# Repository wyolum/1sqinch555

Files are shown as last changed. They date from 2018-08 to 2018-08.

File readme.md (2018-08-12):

# 1sqinch555
3x3x3 LED cube without using microcontroller.
Uses the awesome 555 timer and a 14 bit ripple counter (4020).
9 outputs from the counter drive sets of 3 LEDs in series.
Works off 9V battery.
Possible submission for 1 square inch competition at HAD.

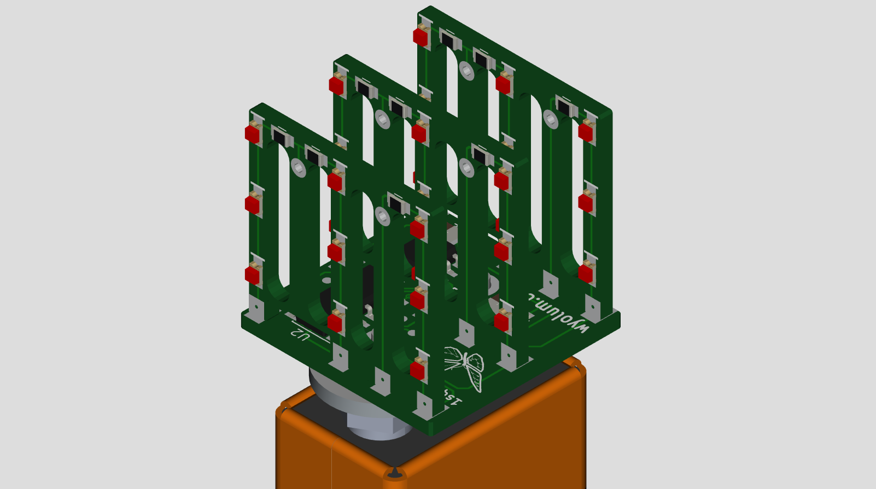
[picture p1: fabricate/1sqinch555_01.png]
1sqinch555


License
-------
[CERN Open Hardware Licence v1.2 ]

[CERN Open Hardware Licence v1.2 ]:http://www.ohwr.org/attachments/2388/cern_ohl_v_1_2.txt

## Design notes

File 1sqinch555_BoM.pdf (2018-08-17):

1sqinch555_pcb_BoM

Page 1

No | Quantity Reference | Value | Footprint
1 | 1 | BT1 | 9V | 9V_clip_968
2 | 1 | C1 | 10uF | C_0805
3 | 1 | C2 | 10nF | C_0805
4 | 27 | D1,D2,D3,D4,D5,D6,D7,D8,D 9,D10,D11,D12,D13,D14,D15 ,D16,D17,D18,D19,D20,D21, D22,D23,D24,D25,D26,D27 | LED | D_0805
5 | 1 | R1 | 33k | R_0805
6 | 9 | R2,R3,R4,R5,R6,R7,R8,R9,R 10 | 300 | R_0805
7 | 1 | U1 | LM555 | SOIC-8_3.9x4.9mm_Pitch1.27mm
8 | 1 | U2 | 4020 | SOIC-16_3.9x9.9mm_Pitch1.27mm

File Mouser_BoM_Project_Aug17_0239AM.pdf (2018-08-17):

1SQINCH555
Mouser No | Mfr. No | Manufacturer
534-967 | 967 | Keystone Electronics
595-SA555DR | SA555DR | Texas Instruments
771-HEC4020BT118 | HEC4020BT,118 | Nexperia
667-ERJ-6ENF3302V | ERJ-6ENF3302V | Panasonic
71-CRCW0805300RJNEA | CRCW0805300RJNEA | Vishay
77-VJ0805Y103MXXCBC | VJ0805Y103MXXCW1BC Vishay
710-150080RS75000 | 150080RS75000 | Wurth Electronics
963-TMK212BBJ106MG-T | TMK212BBJ106MG-T | Taiyo Yuden

Customer No

Description
9V Battery Snaps & Contacts 968 w/ .120 legs
Timers & Support Products Precision
Counter ICs 14-ST BINARY COUNTER
Thick Film Resistors - SMD 0805 33Kohms 1% AEC-Q200
Thick Film Resistors - SMD 1/8watt 300ohms 5%
Multilayer Ceramic Capacitors MLCC - SMD/SMT 0805 0.01uF 25volts X7R 20% Standard LEDs - SMD WL-SMCW SMDMono TpVw Waterclr 0805 Red Multilayer Ceramic Capacitors MLCC - SMD/SMT 10uF 25V X5R 20% 0805

RoHS | Lifecycle | Order Qty. Price (USD)Ext.: (USD)
RoHS Compliant | | 5 $1.11 | $5.55
RoHS Compliant | | 1 $0.39 | $0.39
RoHS Compliant | | 1 $0.67 | $0.67
RoHS Compliant By Exemption | | 10 $0.046 | $0.46
RoHS Compliant By Exemption | | 10 $0.042 | $0.42
RoHS Compliant | | 10 $0.10 | $1.00
RoHS Compliant | | 30 $0.171 | $5.13
RoHS Compliant | New Product | 10 $0.077 | $0.77

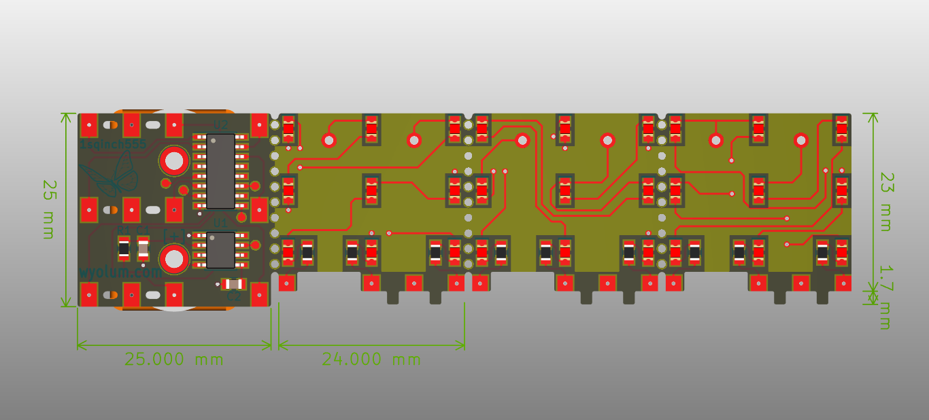
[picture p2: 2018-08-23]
render/1sqinch555_03.png

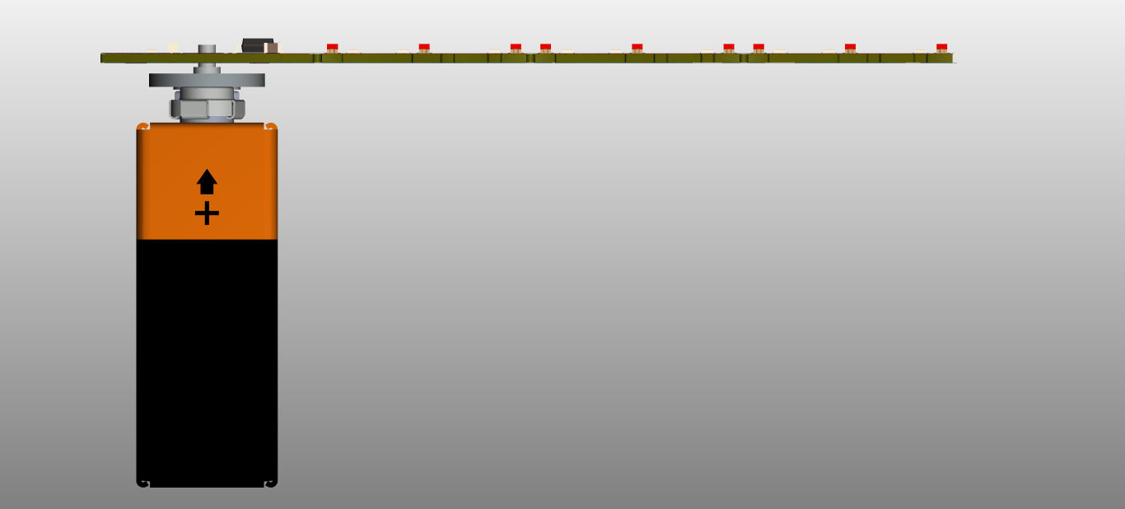
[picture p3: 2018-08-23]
render/1sqinch555_04.png

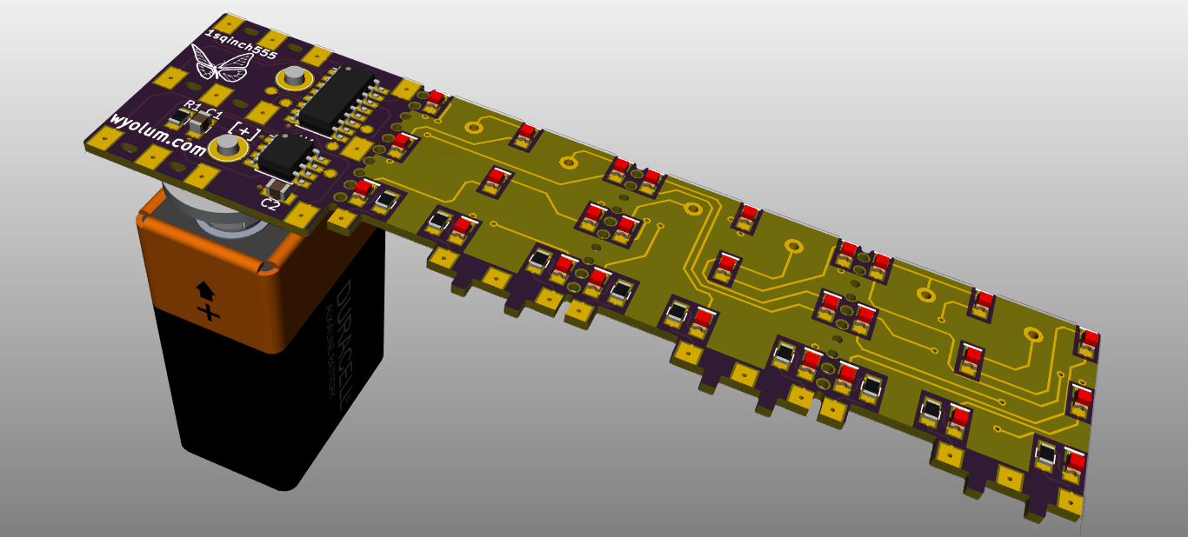
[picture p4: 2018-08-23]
render/1sqinch555_02.png

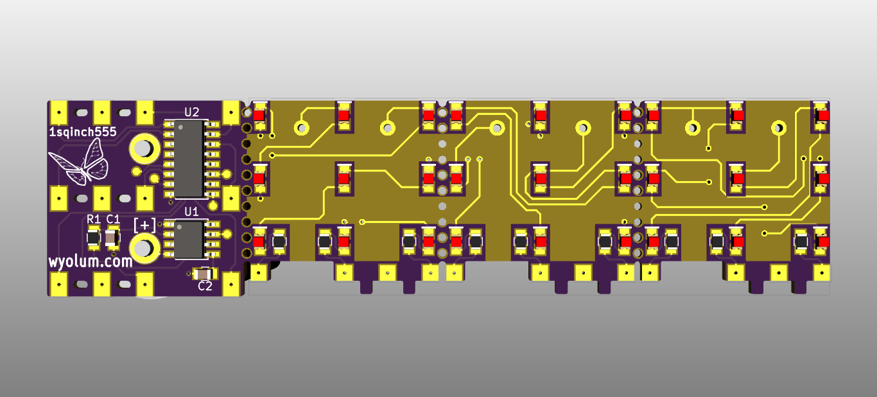
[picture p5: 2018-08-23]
render/1sqinch555_01.png

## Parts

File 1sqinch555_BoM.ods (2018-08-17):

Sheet: 1sqinch555_pcb_BoM
No | Quantity | Reference | Value | Footprint
1 | 1 | BT1 | 9V | 9V_clip_968
2 | 1 | C1 | 10uF | C_0805
3 | 1 | C2 | 10nF | C_0805
4 | 27 | D1,D2,D3,D4,D5,D6,D7,D8,D9,D10,D11,D12,D13,D14,D15,D16,D17,D18,D19,D20,D21,D22,D23,D24,D25,D26,D27 | LED | D_0805
5 | 1 | R1 | 33k | R_0805
6 | 9 | R2,R3,R4,R5,R6,R7,R8,R9,R10 | 300 | R_0805
7 | 1 | U1 | LM555 | SOIC-8_3.9x4.9mm_Pitch1.27mm
8 | 1 | U2 | 4020 | SOIC-16_3.9x9.9mm_Pitch1.27mm

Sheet: 1sqinch555_sch_BoM
No | Quantity | Reference | Value | Footprint
1 | 1 | BT1 | 9V | 1sqinch555_fp:9V_clip_968
2 | 1 | C1 | 10uF | 1sqinch555_fp:C_0805
3 | 1 | C2 | 10nF | 1sqinch555_fp:C_0805
4 | 27 | D1,D2,D3,D4,D5,D6,D7,D8,D9,D10,D11,D12,D13,D14,D15,D16,D17,D18,D19,D20,D21,D22,D23,D24,D25,D26,D27 | LED | 1sqinch555_fp:D_0805
5 | 1 | R1 | 33k | 1sqinch555_fp:R_0805
6 | 9 | R2,R3,R4,R5,R6,R7,R8,R9,R10 | 300 | 1sqinch555_fp:R_0805
7 | 1 | U1 | LM555 | 1sqinch555_fp:SOIC-8_3.9x4.9mm_Pitch1.27mm
8 | 1 | U2 | 4020 | 1sqinch555_fp:SOIC-16_3.9x9.9mm_Pitch1.27mm

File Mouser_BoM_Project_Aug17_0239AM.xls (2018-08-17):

1SQINCH555
Mouser No | Mfr. No | Manufacturer | Customer No | Description | RoHS | Lifecycle | Order Qty. | Price (USD) | Ext.: (USD)
534-967 | 967 | Keystone Electronics |  | 9V Battery Snaps & Contacts 968 w/ .120 legs | RoHS Compliant |  | 5 | $1.11 | $5.55
595-SA555DR | SA555DR | Texas Instruments |  | Timers & Support Products Precision | RoHS Compliant |  | 1 | $0.39 | $0.39
771-HEC4020BT118 | HEC4020BT,118 | Nexperia |  | Counter ICs 14-ST BINARY COUNTER | RoHS Compliant |  | 1 | $0.67 | $0.67
667-ERJ-6ENF3302V | ERJ-6ENF3302V | Panasonic |  | Thick Film Resistors - SMD 0805 33Kohms 1% AEC-Q200 | RoHS Compliant By Exemption |  | 10 | $0.046 | $0.46
71-CRCW0805300RJNEA | CRCW0805300RJNEA | Vishay |  | Thick Film Resistors - SMD 1/8watt 300ohms 5% | RoHS Compliant By Exemption |  | 10 | $0.042 | $0.42
77-VJ0805Y103MXXCBC | VJ0805Y103MXXCW1BC | Vishay |  | Multilayer Ceramic Capacitors MLCC - SMD/SMT 0805 0.01uF 25volts X7R 20% | RoHS Compliant |  | 10 | $0.10 | $1.00
710-150080RS75000 | 150080RS75000 | Wurth Electronics |  | Standard LEDs - SMD WL-SMCW SMDMono TpVw Waterclr 0805 Red | RoHS Compliant |  | 30 | $0.171 | $5.13
963-TMK212BBJ106MG-T | TMK212BBJ106MG-T | Taiyo Yuden |  | Multilayer Ceramic Capacitors MLCC - SMD/SMT 10uF 25V X5R 20% 0805 | RoHS Compliant | New Product | 10 | $0.077 | $0.77

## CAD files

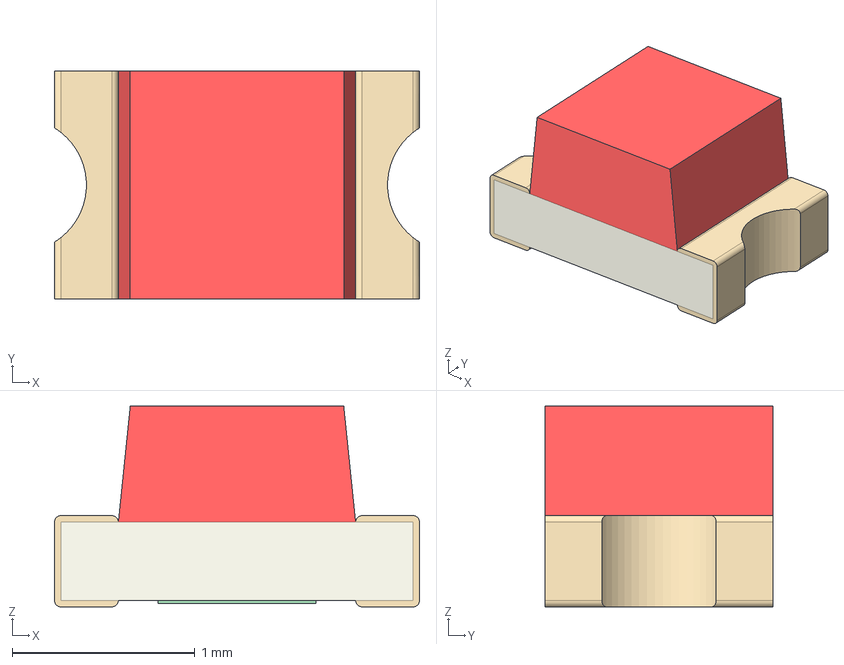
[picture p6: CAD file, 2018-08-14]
3d_modules/LED_0805_2012Metric_Castellated.step
2.00 x 1.25 x 1.10 mm

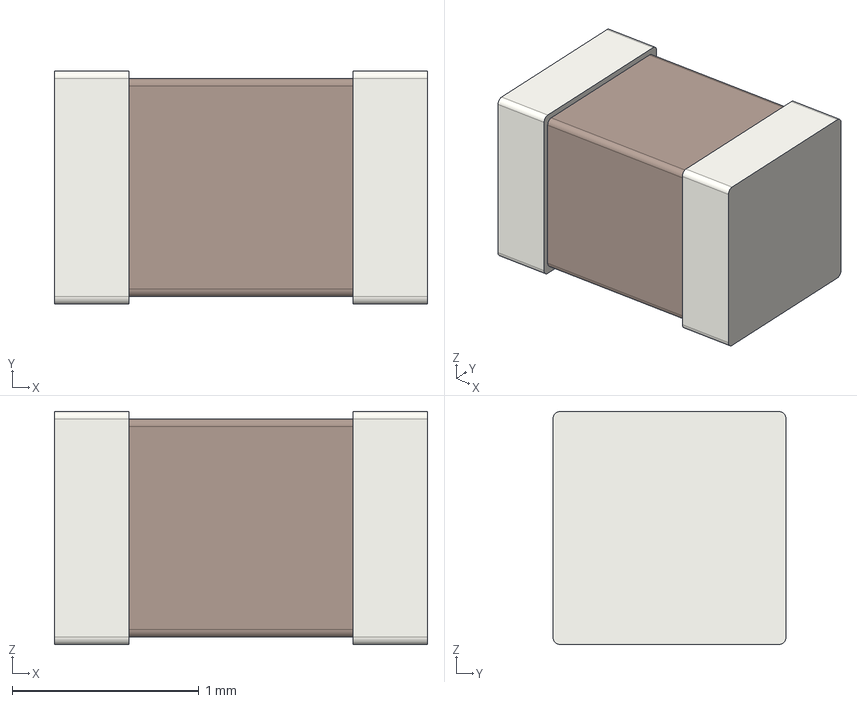
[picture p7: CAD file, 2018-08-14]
3d_modules/C_0805_2012Metric.step
2.00 x 1.25 x 1.25 mm

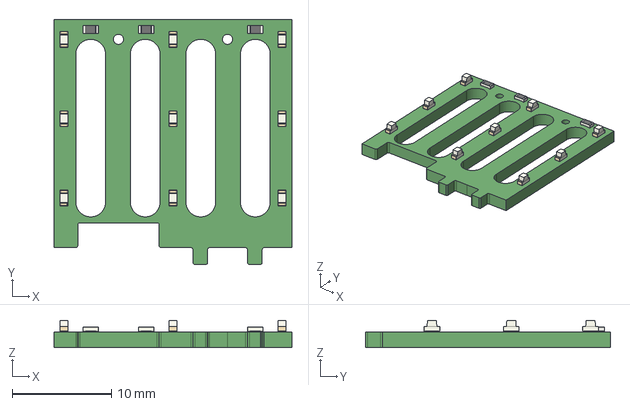
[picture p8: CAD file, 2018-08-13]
fabricate/1sqinch555_LED.step
24.0 x 24.7 x 2.75 mm

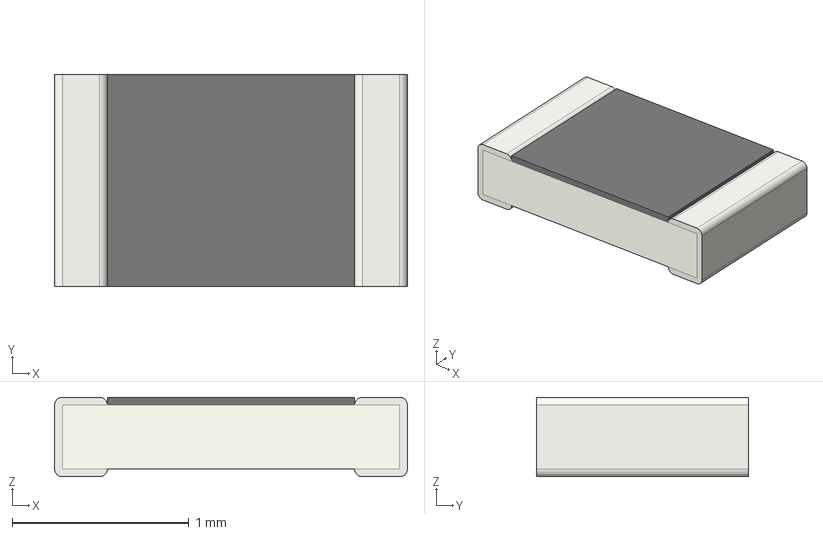
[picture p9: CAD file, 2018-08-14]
3d_modules/R_0805_2012Metric.step
2.00 x 1.20 x 0.45 mm

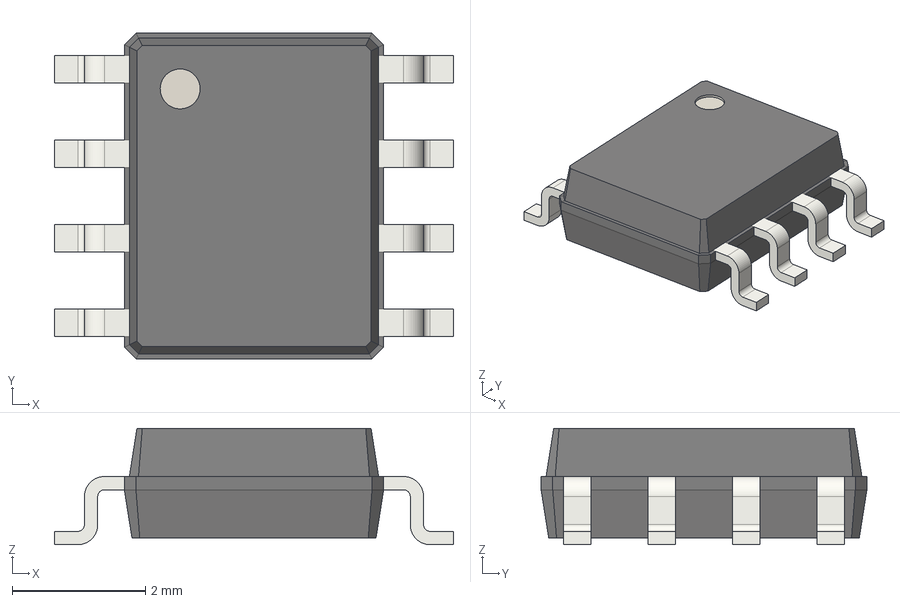
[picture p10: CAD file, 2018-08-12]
3d_modules/SOIC-8_3.9x4.9mm_P1.27mm.step
6.00 x 4.90 x 1.75 mm

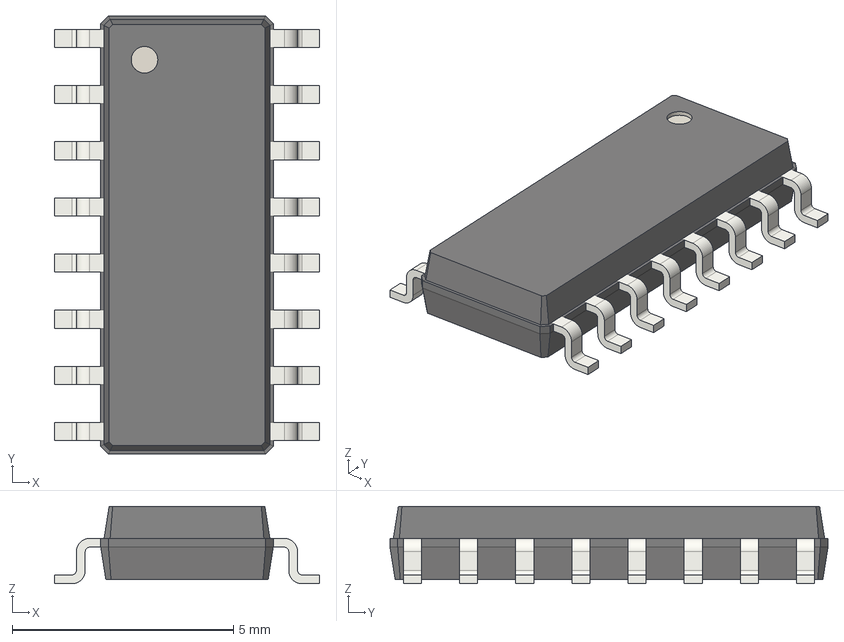
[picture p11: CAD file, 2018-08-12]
3d_modules/SOIC-16_3.9x9.9mm_P1.27mm.step
6.00 x 9.90 x 1.75 mm

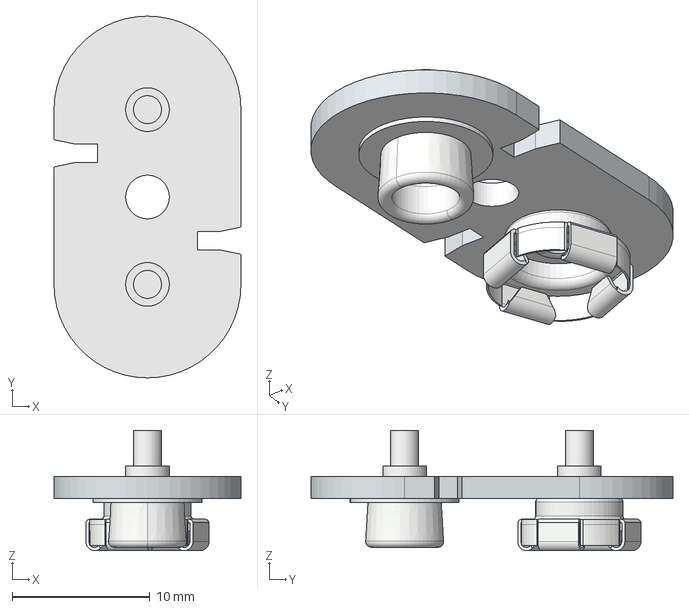
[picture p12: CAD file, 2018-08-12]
3d_modules/batt_9V.step
13.6 x 26.3 x 8.75 mm

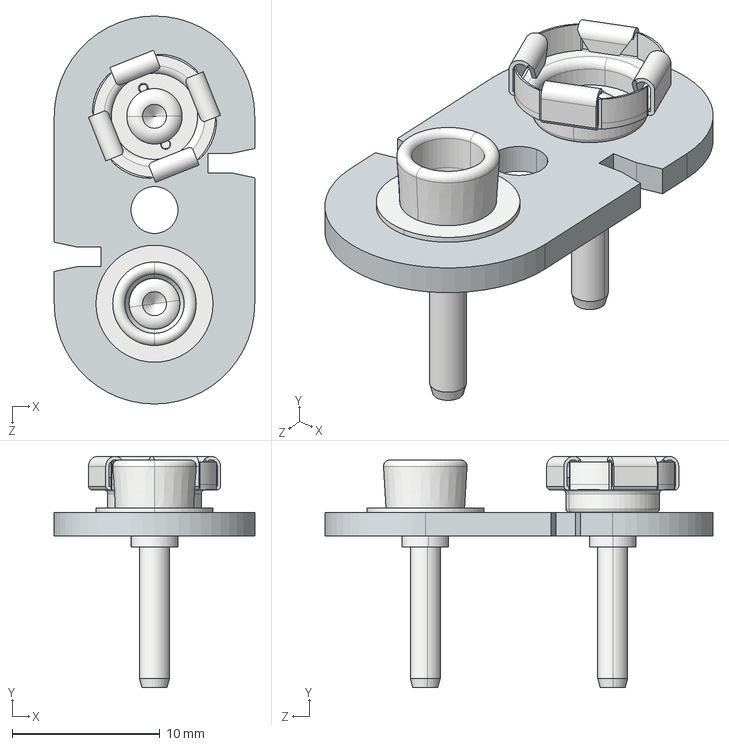
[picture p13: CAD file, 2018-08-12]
3d_modules/keystone-PN968.stp
13.6 x 15.7 x 26.3 mm

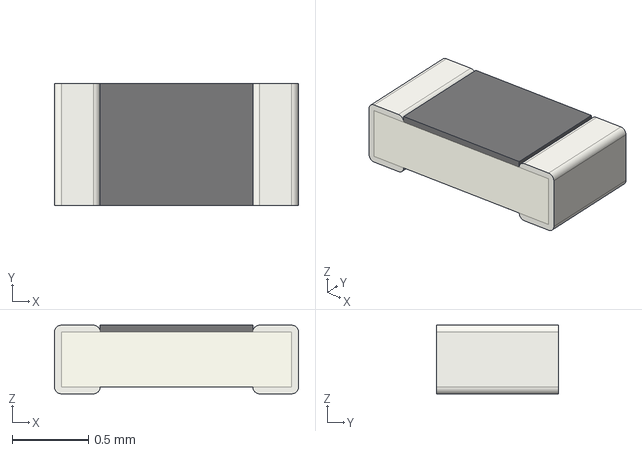
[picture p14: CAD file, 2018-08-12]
3d_modules/R_0603_1608Metric.step
1.60 x 0.8 x 0.45 mm

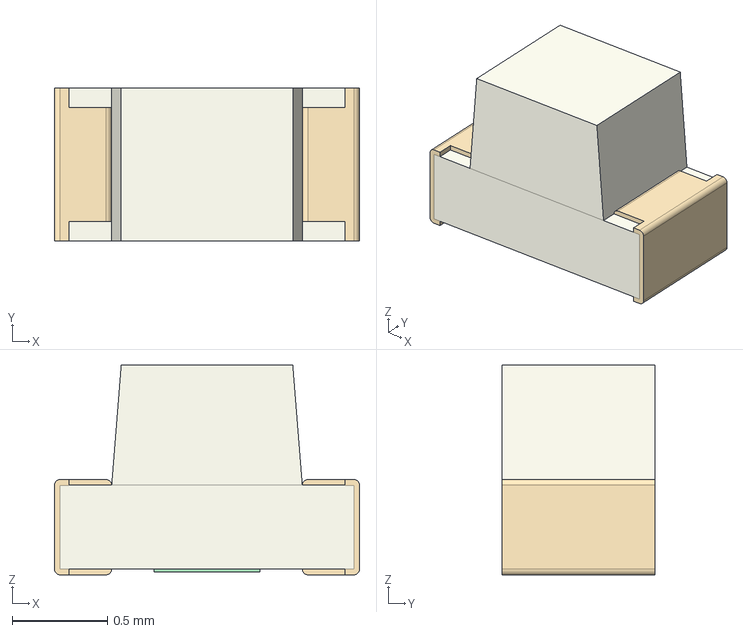
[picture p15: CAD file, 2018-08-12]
3d_modules/LED_0603_1608Metric.step
1.60 x 0.8 x 1.10 mm

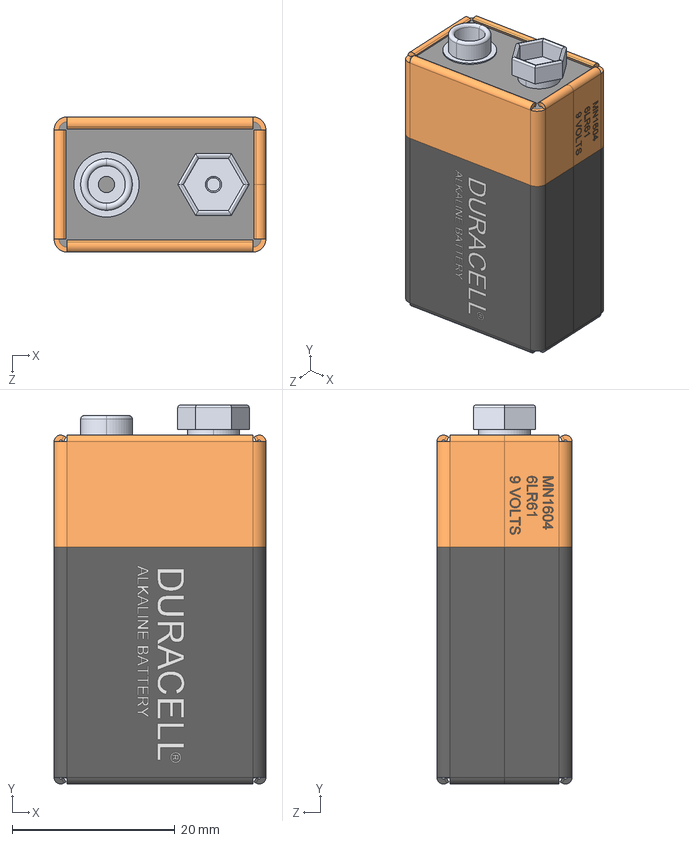
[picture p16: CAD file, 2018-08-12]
3d_modules/9V Duracell Battery.step
26.0 x 46.5 x 16.6 mm

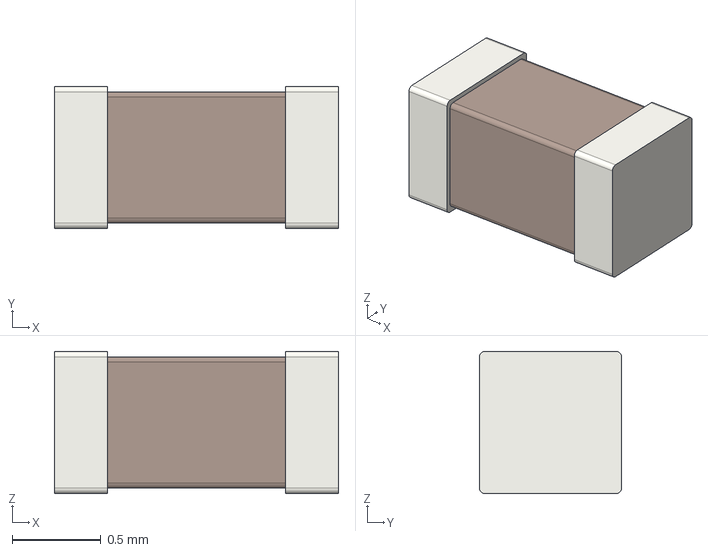
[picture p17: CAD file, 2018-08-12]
3d_modules/C_0603_1608Metric.step
1.60 x 0.8 x 0.8 mm

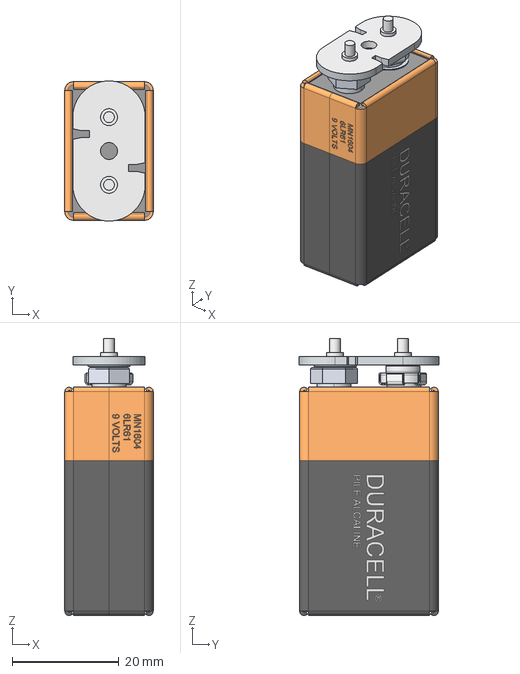
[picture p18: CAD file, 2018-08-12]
3d_modules/batt_9V_cp.step
16.6 x 26.3 x 52.0 mm

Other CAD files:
fabricate/1sqinch555.fcstd

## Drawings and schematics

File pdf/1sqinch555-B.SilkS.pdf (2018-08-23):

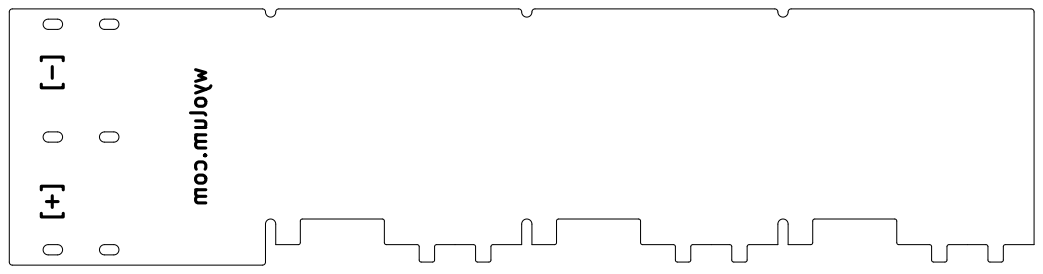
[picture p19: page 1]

File: 1sqinch555.kicad_pcb Sheet: wyolum.com [+] [-]

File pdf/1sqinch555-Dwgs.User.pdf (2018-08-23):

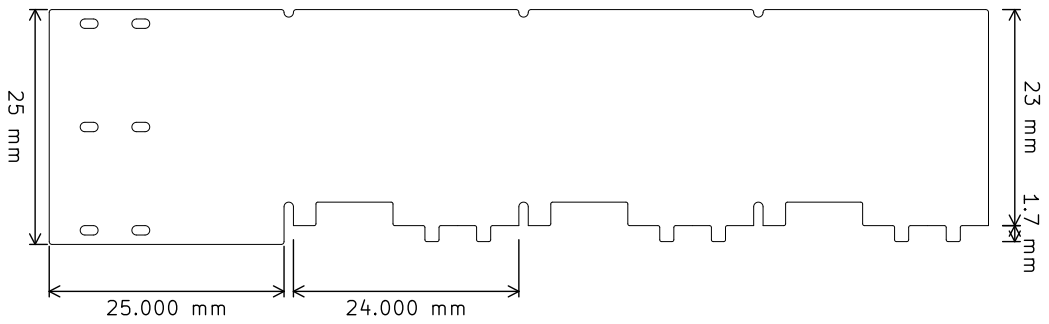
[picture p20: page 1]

File: 1sqinch555.kicad_pcb Sheet: 1.7 mm 23 mm

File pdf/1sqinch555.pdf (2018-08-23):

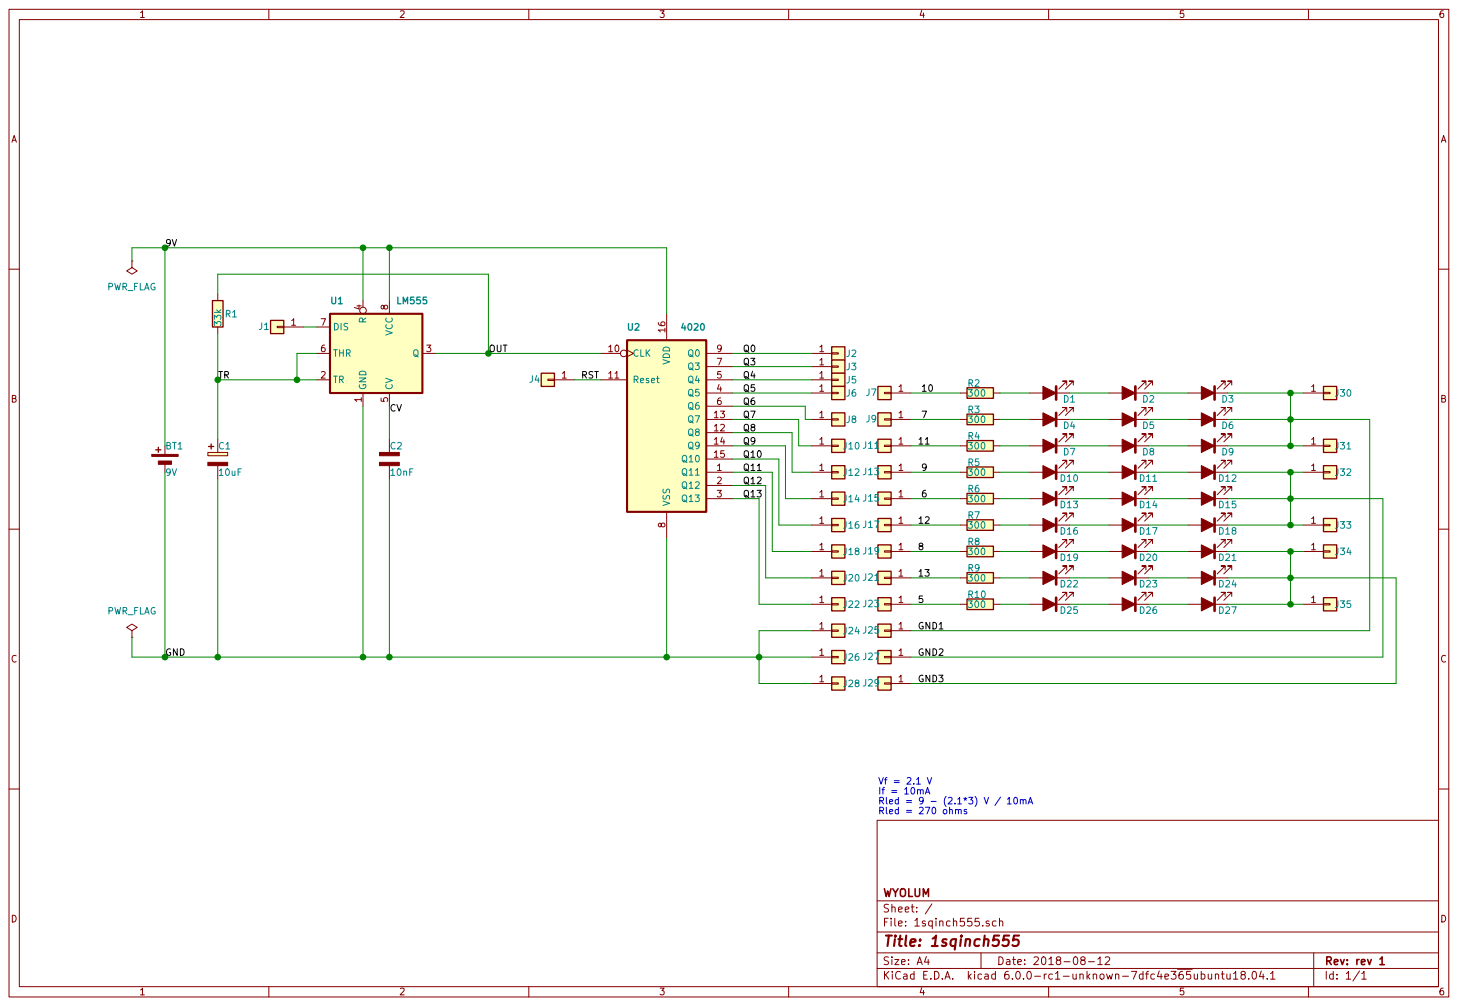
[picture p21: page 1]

If = 10mA Rled = 9 - (2.1*3) V / 10mA Rled = 270 ohms

File: 1sqinch555.sch Sheet: / WYOLUM

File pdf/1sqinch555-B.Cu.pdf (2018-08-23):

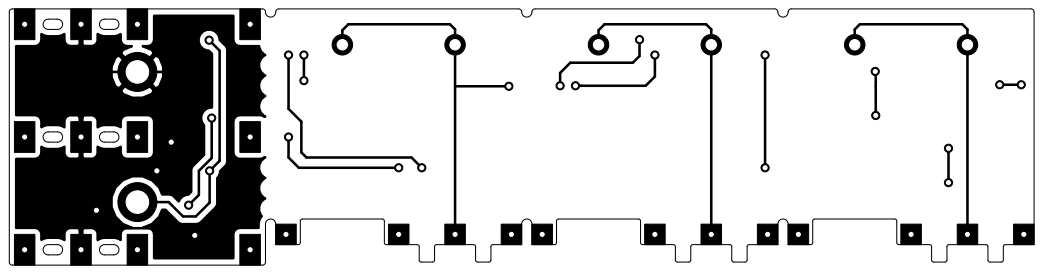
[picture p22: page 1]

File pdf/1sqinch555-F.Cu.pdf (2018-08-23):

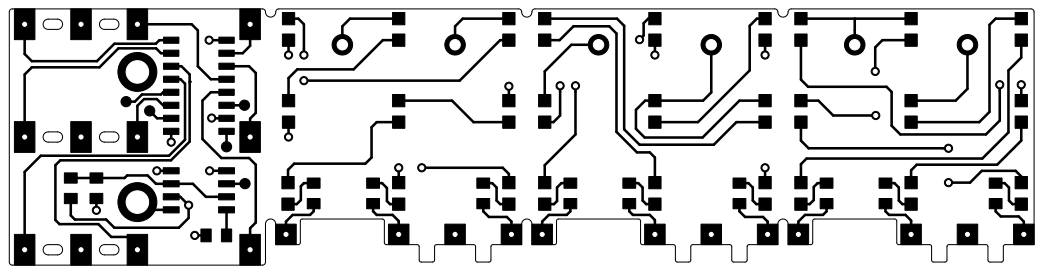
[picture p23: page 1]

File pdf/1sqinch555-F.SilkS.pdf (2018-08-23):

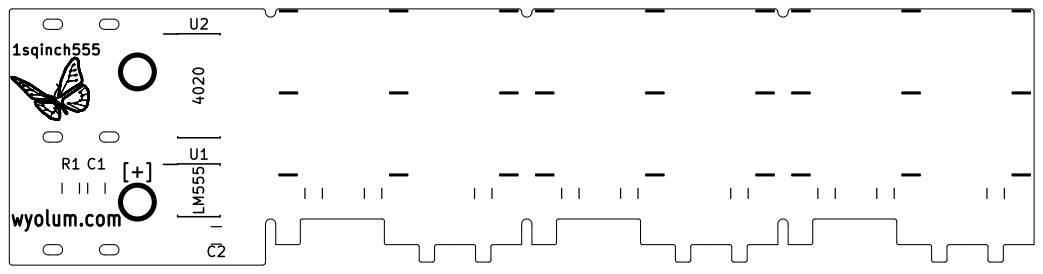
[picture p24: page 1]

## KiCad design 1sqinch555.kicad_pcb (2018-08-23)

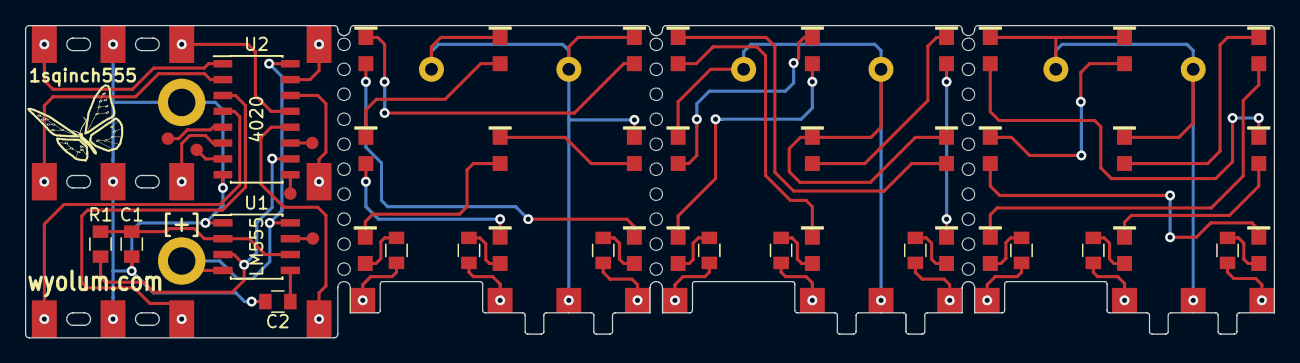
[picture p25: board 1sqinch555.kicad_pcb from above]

Board: 2 copper layers, 100.0 x 25.0 mm, 78 parts (0 on the bottom side), 58 nets.

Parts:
BT1: 9V; 9V_clip_968
C1: 10uF; C_0805
C2: 10nF; C_0805
D1, D2, D3, D4, D5, D6, D7, D8, D9, D10, D11, D12, D13, D14, D15, D16, D17, D18, D19, D20, D21, D22, D23, D24, D25, D26, D27: LED; LED-0805
G1: Logo-WL3
J1, J2, J3, J4, J5: Conn_01x01; pad_smd_1mm
J6, J8, J10, J12, J14, J16, J18, J20, J22, J24, J26, J28: Conn_01x01; pad_3x2mm_smd
J7, J9, J11, J13, J15, J17, J19, J21, J23, J25, J27, J29: Conn_01x01; pad_2x2mm
J30, J31, J32, J33, J34, J35: Conn_01x01; Plated_Hole_d1.0mm
R1: 33k; R_0805
R2, R3, R4, R5, R6, R7, R8, R9, R10: 300; R_0805
U1: LM555; SOIC-8_3.9x4.9mm_Pitch1.27mm
U2: 4020; SOIC-16_3.9x9.9mm_Pitch1.27mm

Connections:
/5: J23.1, R10.2
/6: J15.1, R6.2
/7: J9.1, R3.2
/8: J19.1, R8.2
/9: J13.1, R5.2
/9V: BT1.1, U1.4, U1.8, U2.16
/10: J7.1, R2.2
/11: J11.1, R4.2
/12: J17.1, R7.2
/13: J21.1, R9.2
/CV: C2.1, U1.5
/GND: BT1.2, C1.2, C2.2, J24.1, J26.1, J28.1, U1.1, U2.8
/GND1: D3.1, D6.1, D9.1, J25.1, J30.1, J31.1
/GND2: D12.1, D15.1, D18.1, J27.1, J32.1, J33.1
/GND3: D21.1, D24.1, D27.1, J29.1, J34.1, J35.1
/OUT: R1.1, U1.3, U2.10
/Q0: J2.1, U2.9
/Q3: J3.1, U2.7
/Q4: J5.1, U2.5
/Q5: J6.1, U2.4
/Q6: J8.1, U2.6
/Q7: J10.1, U2.13
/Q8: J12.1, U2.12
/Q9: J14.1, U2.14
/Q10: J16.1, U2.15
/Q11: J18.1, U2.1
/Q12: J20.1, U2.2
/Q13: J22.1, U2.3
/RST: J4.1, U2.11
/TR: C1.1, R1.2, U1.2, U1.6
unnamed: D1.1, D2.2
unnamed: D1.2, R2.1
unnamed: D2.1, D3.2
unnamed: D4.1, D5.2
unnamed: D4.2, R3.1
unnamed: D5.1, D6.2
unnamed: D7.1, D8.2
unnamed: D7.2, R4.1
unnamed: D8.1, D9.2
unnamed: D10.1, D11.2
unnamed: D10.2, R5.1
unnamed: D11.1, D12.2
unnamed: D13.1, D14.2
unnamed: D13.2, R6.1
unnamed: D14.1, D15.2
unnamed: D16.1, D17.2
unnamed: D16.2, R7.1
unnamed: D17.1, D18.2
unnamed: D19.1, D20.2
unnamed: D19.2, R8.1
unnamed: D20.1, D21.2
unnamed: D22.1, D23.2
unnamed: D22.2, R9.1
unnamed: D23.1, D24.2
unnamed: D25.1, D26.2
unnamed: D25.2, R10.1
unnamed: D26.1, D27.2
unnamed: J1.1, U1.7

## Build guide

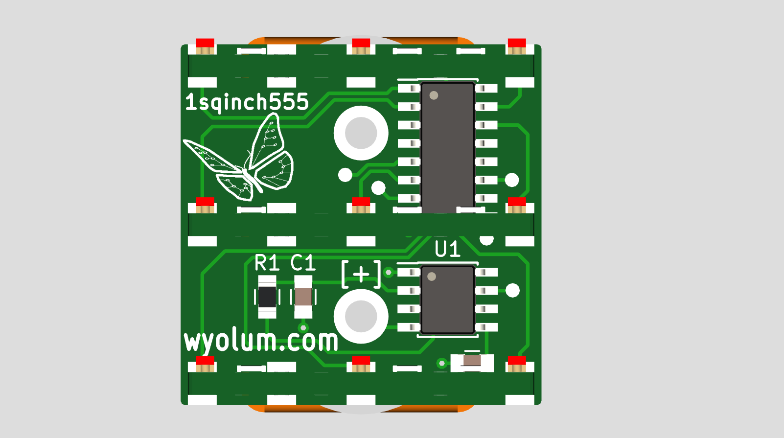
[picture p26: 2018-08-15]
fabricate/1sqinch555_04.png

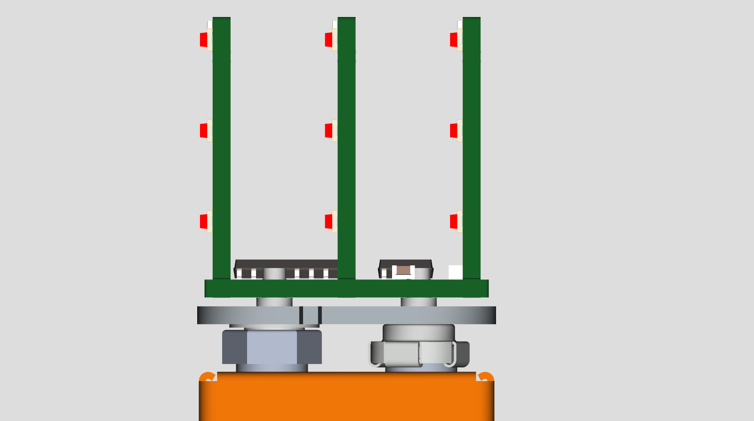
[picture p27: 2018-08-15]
fabricate/1sqinch555_03.png

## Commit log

2018-08-12 initial commit, a 1 sq inch 555 timer project
    [1sqinch555-B.Cu.gbl, 1sqinch555-B.Cu.gbr, 1sqinch555-B.Mask.gbr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]
2018-08-12 added schematic to pdf folder
2018-08-12 regenerated gerbers
    [1sqinch555-B.Cu.gbr, 1sqinch555-B.Mask.gbr, 1sqinch555-B.SilkS.gbr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]
2018-08-13 BoM update
    [1sqinch555.kicad_pcb]
2018-08-13 changed 0603 to 0805
    [1sqinch555-B.Cu.gbl, 1sqinch555-B.Cu.gbr, 1sqinch555-B.Mask.gbr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]
2018-08-14 layout changes
    [1sqinch555-B.Cu.gbl, 1sqinch555-B.Cu.gbr, 1sqinch555-B.Mask.gbr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]
2018-08-17 BoM updates
    [1sqinch555.sch, 1sqinch555_BoM.ods, 1sqinch555_pcb_BoM.csv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]
2018-08-21 randomizing LEDs
    [1sqinch555.kicad_pcb]
2018-08-23 1mm PCB thickness
    [1sqinch555-B.Cu.gbl, 1sqinch555-B.Mask.gbr, 1sqinch555-B.Mask.gbs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]

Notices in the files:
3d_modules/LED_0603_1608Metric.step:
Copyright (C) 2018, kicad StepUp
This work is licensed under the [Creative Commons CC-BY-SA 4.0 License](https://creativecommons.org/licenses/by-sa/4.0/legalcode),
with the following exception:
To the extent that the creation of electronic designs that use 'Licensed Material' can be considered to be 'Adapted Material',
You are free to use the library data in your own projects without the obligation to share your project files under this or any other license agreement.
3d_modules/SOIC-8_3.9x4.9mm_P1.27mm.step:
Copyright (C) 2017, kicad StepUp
